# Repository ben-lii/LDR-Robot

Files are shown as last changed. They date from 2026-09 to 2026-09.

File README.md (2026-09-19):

# Teleop robot

Browser-driven Raspberry Pi robot: live WebRTC video and WASD motor control.

Local development and deploy steps will be filled in as the app is built. See `docs/` for architecture, protocol, hardware, and Pi setup.

## Workspaces

- `web/` — Next.js console (Vercel)
- `robot/` — Node server on the Pi
- `packages/protocol` — shared contracts

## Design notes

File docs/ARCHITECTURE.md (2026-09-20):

# Architecture

No database. Users and robots live in validated env JSON on the web app;
runtime drive/media state lives in memory on the robot.

## Planes

1. **Auth / session (web)** — login cookie, control-token minting, ICE list.
   Never on the real-time path except token refresh.
2. **Control (WebSocket)** — browser ↔ robot Node server. Seat, drive, e-stop,
   watchdog. Continuously authorized via hello + `token_refresh`.
3. **Media (WHEP / WebRTC)** — browser POSTs SDP to robot `/whep`; Node checks
   the bearer token once, then proxies to local MediaMTX. An already-running
   video session is **not** continuously re-checked; control is.

## Local media

`MEDIA_MODE=disabled` → `/whep` returns `503 video_unavailable` (UI shows
"Video unavailable"). Laptop webcam testing: see `docs/LOCAL_VIDEO.md`.

## Pi deployment

End-to-end OS / systemd / tunnel steps: `docs/PI_SETUP.md`.  
Wiring and power: `docs/HARDWARE.md`. On the Pi prefer `MOTOR_DRIVER=gpiod`
(`rpi-io` + soft PWM, Trixie-friendly). Legacy `MOTOR_DRIVER=pigpio` remains for
Bookworm / self-built pigpio. Both are optional native deps loaded only via
dynamic import; laptops use `mock`.

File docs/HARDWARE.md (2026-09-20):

# Hardware

Raspberry Pi Zero 2 W teleop robot: camera, mic, DRV8833, two N20 motors.

## Bill of materials (reference)

| Part | Role |
| --- | --- |
| Raspberry Pi Zero 2 W | Compute, Wi‑Fi, GPIO |
| OV5647 camera module | CSI video (H.264 via `rpicam-vid`) |
| I2S MEMS microphone | Robot listen-back audio |
| DRV8833 dual H-bridge | Motor driver |
| 2× N20 gearmotors | Differential / tank drive |
| Separate motor battery + 5 V logic supply | Split rails, **shared ground** |

## GPIO map (BCM) — defaults in `robot/.env`

| Signal | BCM | DRV8833 / notes |
| --- | --- | --- |
| Left IN1 (`PIN_AIN1`) | 5 | PWM or digital |
| Left IN2 (`PIN_AIN2`) | 6 | PWM or digital |
| Right IN1 (`PIN_BIN1`) | 13 | PWM or digital |
| Right IN2 (`PIN_BIN2`) | 26 | PWM or digital |
| nSLEEP (`PIN_SLEEP`) | optional | High = enabled; omit if tied high in hardware |

Verify against your board silkscreen before powering motors. Change pins only via env — never hard-code elsewhere.

## Motor polarity

Software can fix wiring mistakes without rewiring:

- `INVERT_LEFT` / `INVERT_RIGHT` — flip that side’s sign  
- `SWAP_MOTORS` — swap left/right after mix  

`MIN_DRIVE_DUTY` (default `0.25`) lifts small commands so N20s overcome stiction.
`PWM_FREQUENCY_HZ` defaults to `1000`; with `MOTOR_DRIVER=gpiod` soft PWM is
clamped to 400 Hz (userspace timers). `pigpio` may round to a supported rate.

## Drive truth table (DRV8833)

| Mode | IN1 | IN2 |
| --- | --- | --- |
| Forward | PWM | LOW |
| Reverse | LOW | PWM |
| Coast | LOW | LOW |
| Brake | HIGH | HIGH |

## Power (critical)

- **Logic rail** (Pi 5 V / 3.3 V GPIO) and **motor rail** (battery → VMOT on DRV8833) must be separate supplies.  
- **Connect grounds together** (common GND).  
- Never power motors from the Pi 5 V pin.  
- Add bulk capacitance near the DRV8833 VMOT pins as the module recommends.  
- Fit a physical kill switch / fuse on the motor battery.

## Camera / audio

- Enable camera (and legacy stack notes) in `infra/pi/config.txt.notes.md`.  
- Mic device name is tuned in `/etc/teleop/av.env` (`AUDIO_DEVICE`). Start with `AUDIO_ENABLED=0` until video is stable.

## Safety

- Software watchdog (~300 ms) and e-stop live on the Pi.  
- Hardware still needs a way to cut motor power if software hangs.

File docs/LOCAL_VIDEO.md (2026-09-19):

# Local video test (laptop webcam → MediaMTX → teleop UI)

Yes — you can exercise the full WHEP path on a Windows laptop without a Pi
camera. Publish your webcam (or a test pattern) into MediaMTX, point the robot
proxy at it, and open the console.

## Prerequisites

1. [ffmpeg](https://ffmpeg.org/download.html) on your PATH  
2. [MediaMTX](https://github.com/bluenviron/mediamtx/releases) **v1.12.2** (or
   the pin in `infra/mediamtx/mediamtx.yml`)  
3. Robot + web already working (`npm run dev:robot`, `npm run dev:web`)

## 1. Start MediaMTX

From the repo root:

```powershell
# Download the release zip once, extract mediamtx.exe somewhere on PATH, then:
mediamtx .\infra\mediamtx\mediamtx.yml
```

Leave this terminal open. API: `127.0.0.1:9997`, WHEP: `127.0.0.1:8889`,
RTSP publish: `127.0.0.1:8554`.

## 2. Publish the webcam

List DirectShow devices:

```powershell
ffmpeg -list_devices true -f dshow -i dummy
```

Publish (replace the quoted names with yours):

```powershell
ffmpeg -f dshow -video_size 640x480 -framerate 30 `
  -i video="Integrated Camera" `
  -pix_fmt yuv420p `
  -c:v libx264 -profile:v baseline -bf 0 -g 30 -preset ultrafast -tune zerolatency `
  -f rtsp -rtsp_transport tcp rtsp://127.0.0.1:8554/robot
```

Many webcams deliver YUY2 (4:2:2); baseline H.264 needs `yuv420p` — without
`-pix_fmt yuv420p` you'll see `baseline profile doesn't support 4:2:2`.

Video-only is fine. To include a mic, add a second `-i audio="…"` and
`-c:a libopus -ac 1 -b:a 32k`.

No camera? Use a test pattern instead:

```powershell
ffmpeg -re -f lavfi -i testsrc=size=640x480:rate=30 `
  -pix_fmt yuv420p `
  -c:v libx264 -profile:v baseline -bf 0 -g 30 -preset ultrafast -tune zerolatency `
  -f rtsp -rtsp_transport tcp rtsp://127.0.0.1:8554/robot
```

## 3. Enable media on the robot

In `robot/.env`:

```env
MEDIA_MODE=mediamtx
MEDIAMTX_WHEP_URL=http://127.0.0.1:8889
MEDIAMTX_API_URL=http://127.0.0.1:9997
MEDIA_PATH=robot
```

Restart `npm run dev:robot`. Confirm MediaMTX sees the path:

```powershell
curl.exe http://127.0.0.1:9997/v3/paths/get/robot
```

`ready` should be `true` while ffmpeg is publishing.

## 4. Watch in the browser

Open the console (already logged in). You should see **Live** once frames
decode. Click the mic button to unmute robot audio (starts muted for autoplay).

If the badge stays on **Video unavailable**, check `MEDIA_MODE`, that MediaMTX
is running, and that `ALLOWED_ORIGINS` includes `http://localhost:3000`.

## Notes

- Browser ↔ MediaMTX **media** uses UDP **8189** (same machine → usually fine).
  Remote viewers need TURN and/or a forward of UDP 8189 (see TROUBLESHOOTING).
- Token is checked when WHEP connects; an existing video session is not
  continuously re-authorized (control WS is). See ARCHITECTURE.md.

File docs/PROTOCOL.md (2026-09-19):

# Protocol

All WebSocket messages, token claims, HTTP bodies, and shared constants live in `@teleop/protocol`. Both the web app and the robot import this package. Every message is a JSON text frame with `v: 1` and a `type` discriminator.

Unknown `type` values, extra fields on WebSocket messages, out-of-range numbers, oversize frames (`> 2048` bytes), and garbage JSON are rejected. Parsers return a `Result` and never throw.

## Constants

| Name | Value | Meaning |
| --- | ---: | --- |
| `PROTOCOL_VERSION` | `1` | Message `v` field |
| `WS_PATH` | `/ws` | Control WebSocket |
| `WHEP_PATH` | `/whep` | Authenticated WHEP proxy |
| `STATUS_PATH` | `/status` | Authenticated robot status |
| `HEALTH_PATH` | `/healthz` | Unauthenticated liveness |
| `TOKEN_ISSUER` | `teleop-web` | JWT `iss` |
| `TOKEN_ALG` | `ES256` | Control-token algorithm |
| `TOKEN_TTL_S` | `45` | Control-token lifetime |
| `TOKEN_REFRESH_S` | `15` | Client refresh interval |
| `DRIVER_IDLE_RELEASE_S` | `300` | Idle driver releases the seat  |
| `SESSION_COOKIE_NAME` | `teleop_session` | Web login cookie |
| `SESSION_MAX_AGE_S` | `604800` | Login cookie lifetime (7 days) |
| `DRIVE_SEND_HZ` | `20` | Drive command rate |
| `PING_INTERVAL_MS` | `2000` | WebSocket ping interval |
| `DEFAULT_WATCHDOG_MS` | `300` | Motor watchdog |
| `AUTH_TIMEOUT_MS` | `3000` | Time to send `hello` |
| `MAX_WS_MESSAGE_BYTES` | `2048` | Max text-frame size |
| `MAX_WS_MSG_PER_SEC` | `60` | Per-connection rate limit |
| `VIEWER_CAN_ESTOP` | `true` | Viewers may engage e-stop |
| `STATUS_POLL_MS` | `5000` | Browser `/status` poll |
| `OFFLINE_AFTER_FAILED_POLLS` | `2` | Consecutive failures → offline |

WebSocket close codes: `UNAUTHORIZED` 4001, `TOKEN_EXPIRED` 4002, `PROTOCOL_ERROR` 4003, `AUTH_TIMEOUT` 4008, `SUPERSEDED` 4009, `SERVER_BUSY` 4010.

## Client → robot

### `hello`

Must be the first message. The token is never sent in the URL.

```json
{
  "v": 1,
  "type": "hello",
  "token": "<jwt>",
  "clientSessionId": "550e8400-e29b-41d4-a716-446655440000",
  "wantControl": true
}
```

### `request_control`

Viewer with driver permission asks for the seat.

```json
{ "v": 1, "type": "request_control" }
```

### `release_control`

Driver gives up the seat.

```json
{ "v": 1, "type": "release_control" }
```

### `drive`

Sent at `DRIVE_SEND_HZ` while driving. `steer > 0` is right (D). Each valid `drive` from the driver feeds the watchdog. `throttle` and `steer` are in `[-1, 1]`; `speed` is an integer in `[0, 100]`.

```json
{ "v": 1, "type": "drive", "throttle": 1, "steer": 0, "speed": 50 }
```

### `brake`

Level state. Space held = `true`.

```json
{ "v": 1, "type": "brake", "active": true }
```

### `estop`

`engaged: true` is allowed for any authenticated role when `VIEWER_CAN_ESTOP`. `engaged: false` (clear) is drivers only.

```json
{ "v": 1, "type": "estop", "engaged": true }
```

### `ping`

Client timestamp `t` is echoed in `pong` for RTT.

```json
{ "v": 1, "type": "ping", "id": 1, "t": 1726740000123 }
```

### `token_refresh`

Extends authorization. May lower permission (`driver` → `viewer`).

```json
{ "v": 1, "type": "token_refresh", "token": "<jwt>" }
```

## Robot → client

### `welcome`

```json
{
  "v": 1,
  "type": "welcome",
  "robotId": "7c9e6679-7425-40de-944b-e07fc1f90ae7",
  "permission": "driver",
  "role": "driver",
  "limits": { "watchdogMs": 300, "maxSpeedPercent": 100 },
  "state": {
    "mode": "idle",
    "speedPercent": 0,
    "driverPresent": true,
    "mediaReady": true,
    "uptimeS": 12.5
  }
}
```

`permission` is the most this user may do. `role` is the effective seat (`driver` or `viewer`).

### `role_changed`

`reason` is one of `granted`, `seat_taken`, `released`, `permission`, `token`.

```json
{ "v": 1, "type": "role_changed", "role": "viewer", "reason": "seat_taken" }
```

### `state`

Sent on change and every 1 s. `mode` is `idle` | `driving` | `braking` | `estop` | `fault`.

```json
{
  "v": 1,
  "type": "state",
  "state": {
    "mode": "driving",
    "speedPercent": 40,
    "driverPresent": true,
    "mediaReady": true,
    "uptimeS": 88
  }
}
```

### `pong`

```json
{ "v": 1, "type": "pong", "id": 1, "t": 1726740000123 }
```

### `error`

`code` is `UNAUTHORIZED` | `TOKEN_EXPIRED` | `FORBIDDEN_ROLE` | `DRIVER_BUSY` | `BAD_MESSAGE` | `RATE_LIMITED` | `ROBOT_FAULT`.

```json
{
  "v": 1,
  "type": "error",
  "code": "DRIVER_BUSY",
  "message": "Another driver holds the seat",
  "fatal": false
}
```

## Control token (JWT, ES256)

Claims:

| Claim | Meaning |
| --- | --- |
| `iss` | `teleop-web` |
| `aud` | `robot:<robotId>` (exactly one robot) |
| `sub` | user email |
| `perm` | `driver` or `viewer` (maximum allowed)  |
| `sid` | client session id (uuid, one per tab) |
| `jti` | random uuid |
| `iat`, `exp` | unix seconds; `exp = iat + TOKEN_TTL_S` |

Use `audienceFor(robotId)` to build `aud`.

## HTTP: login

`POST /api/auth/login`

```json
{ "email": "me@example.com", "password": "secret" }
```

Non-2xx body for all web APIs:

```json
{ "error": "unauthenticated" }
```

`error` is `unauthenticated` | `not_found` | `bad_request` | `rate_limited` | `server_error`.

## HTTP: session

`POST /api/robots/[slug]/session`

Request:

```json
{ "clientSessionId": "550e8400-e29b-41d4-a716-446655440000" }
```

Response:

```json
{
  "robot": {
    "id": "7c9e6679-7425-40de-944b-e07fc1f90ae7",
    "slug": "robot-1",
    "name": "Robot 1"
  },
  "permission": "driver",
  "token": "<jwt>",
  "tokenExpiresAt": "2026-09-19T13:00:00.000Z",
  "urls": {
    "ws": "wss://robot-1.example.com/ws",
    "whep": "https://robot-1.example.com/whep",
    "status": "https://robot-1.example.com/status"
  },
  "iceServers": [{ "urls": "stun:stun.l.google.com:19302" }],
  "serverTime": "2026-09-19T12:59:15.000Z"
}
```

## HTTP: robot status

`GET /status` (bearer token required)

```json
{
  "v": 1,
  "fwVersion": "0.0.0",
  "uptimeS": 88,
  "mode": "idle",
  "driverPresent": false,
  "mediaReady": true,
  "clockSynced": true,
  "cpuTempC": 47.2,
  "load1": 0.31,
  "memFreeMb": 220,
  "wifiRssiDbm": -62
}
```

Telemetry fields are `null` when unavailable.

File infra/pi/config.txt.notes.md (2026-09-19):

# Notes for /boot/firmware/config.txt (Bookworm) or /boot/config.txt (older).
# Apply, then reboot. Exact lines vary by camera overlay package — verify against
# Raspberry Pi docs for your OS image.

## Camera (OV5647 / CSI)

# Bookworm typically:
#   camera_auto_detect=1
# Or legacy:
#   start_x=1
#   gpu_mem=128
#
# Confirm with: rpicam-hello --list-cameras

## I2S microphone

# Enable I2S and load your codec overlay (board-specific), e.g.:
#   dtparam=i2s=on
#   dtoverlay=googlevoicehat-soundcard
# or whatever overlay your mic HAT documents.
#
# List capture devices after reboot: arecord -l
# Put the device string into /etc/teleop/av.env as AUDIO_DEVICE.

## Performance (optional on Zero 2 W)

#   arm_boost=1

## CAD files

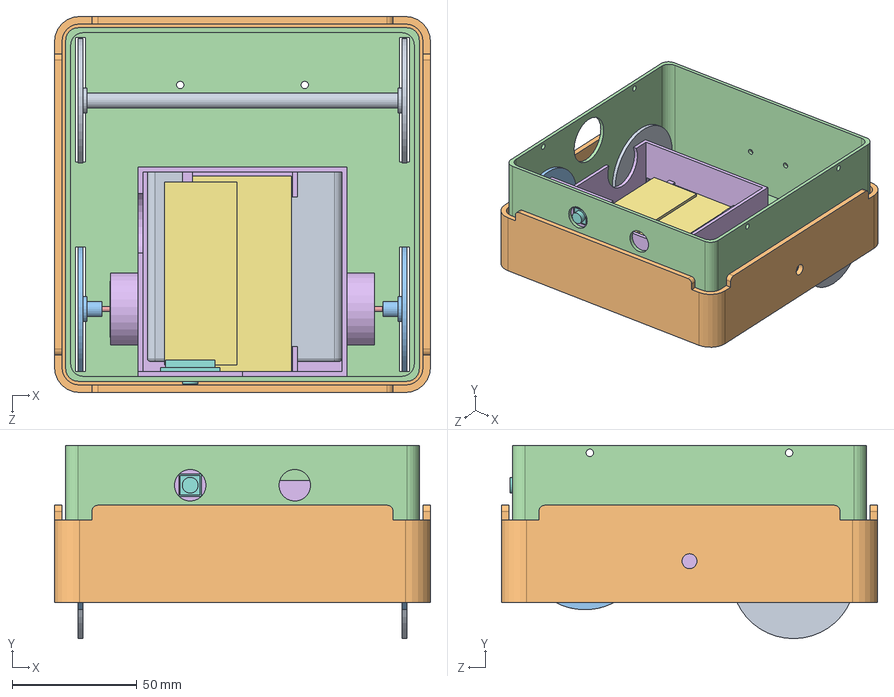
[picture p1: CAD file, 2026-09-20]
Solidworks/whole_robot.SLDASM
151.0 x 77.6 x 151.0 mm
battery
camera_arducam
circut_board
electrical_rig
new_motor x 2
base
bigger_press_fit_wheel x 2
shirt
stabilizer_wheels_2

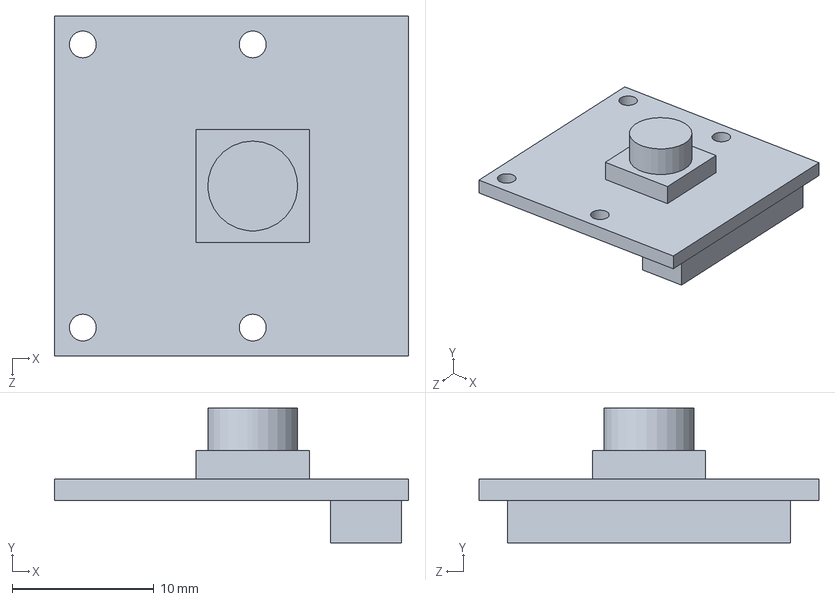
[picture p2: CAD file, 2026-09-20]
Solidworks/camera_arducam.SLDPRT
25.0 x 9.50 x 24.0 mm

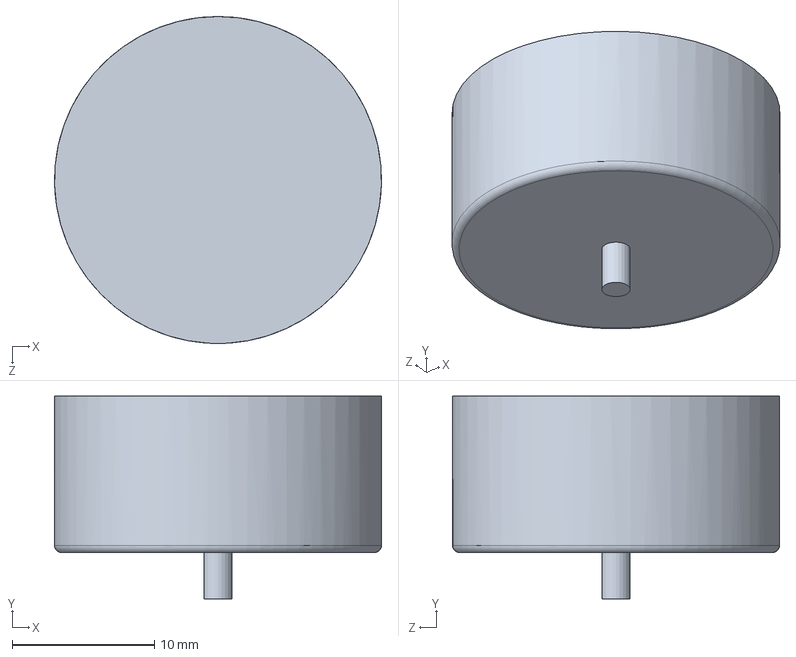
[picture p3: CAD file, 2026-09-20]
Solidworks/new_motor.SLDPRT
23.0 x 14.2 x 23.0 mm

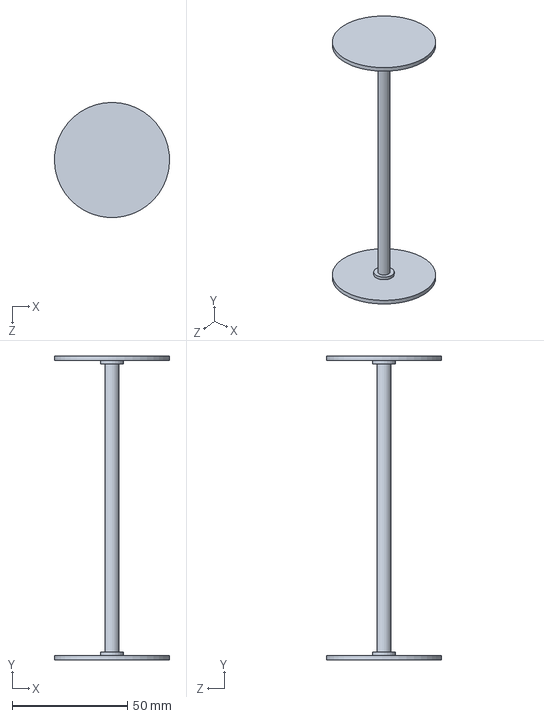
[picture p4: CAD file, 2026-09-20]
Solidworks/stabilizer_wheels_2.SLDPRT
50.0 x 132.0 x 50.0 mm

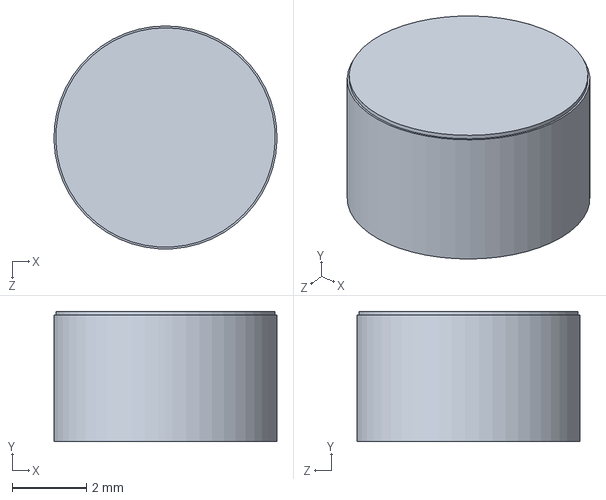
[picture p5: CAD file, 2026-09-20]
Solidworks/microphone.SLDPRT
6.00 x 3.50 x 6.00 mm

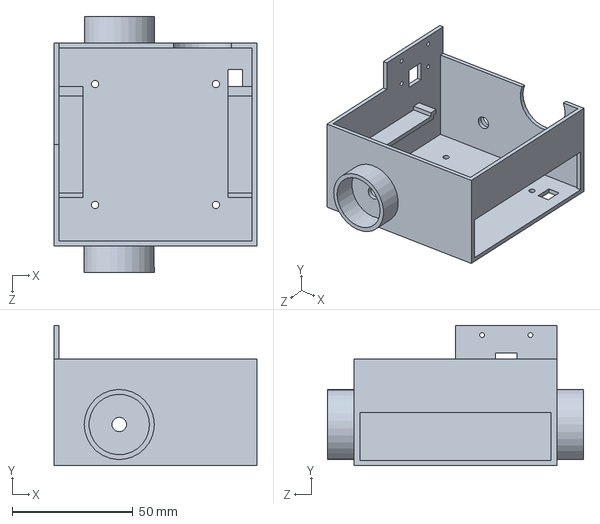
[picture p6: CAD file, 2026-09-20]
Solidworks/electrical_rig.SLDPRT
84.0 x 58.0 x 106.0 mm

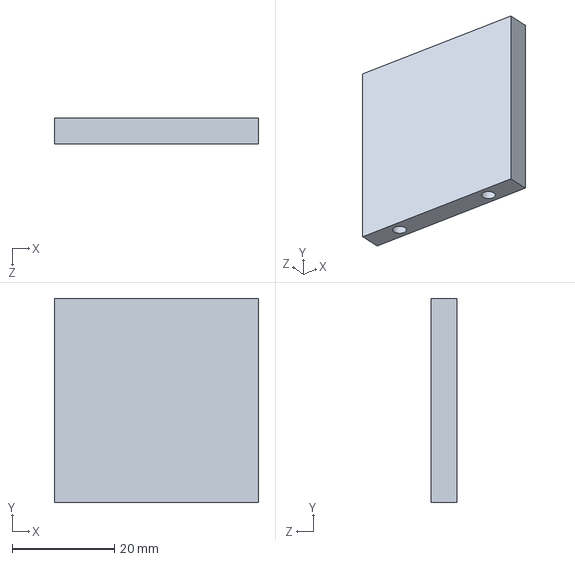
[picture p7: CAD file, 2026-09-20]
Solidworks/slab.SLDPRT
40.0 x 40.0 x 5.00 mm

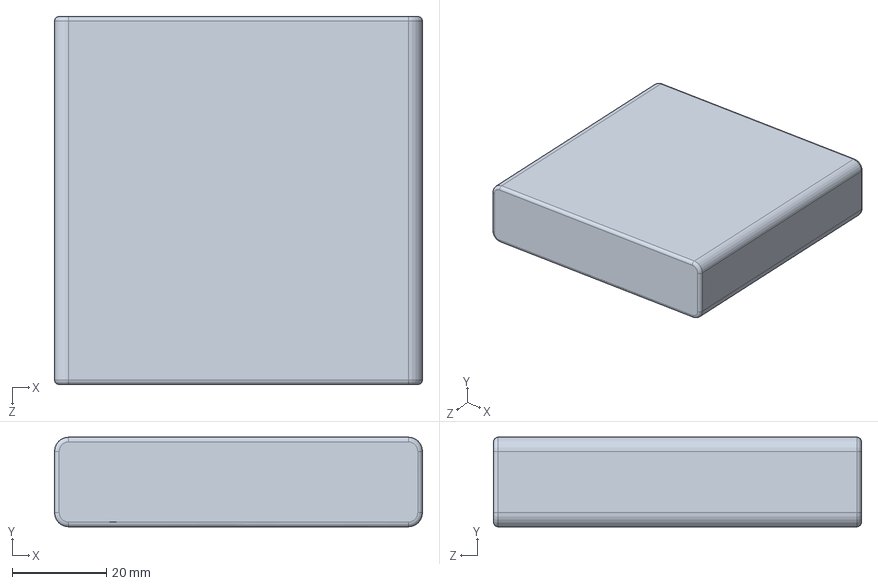
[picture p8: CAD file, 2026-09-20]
Solidworks/battery.SLDPRT
78.0 x 19.0 x 78.0 mm

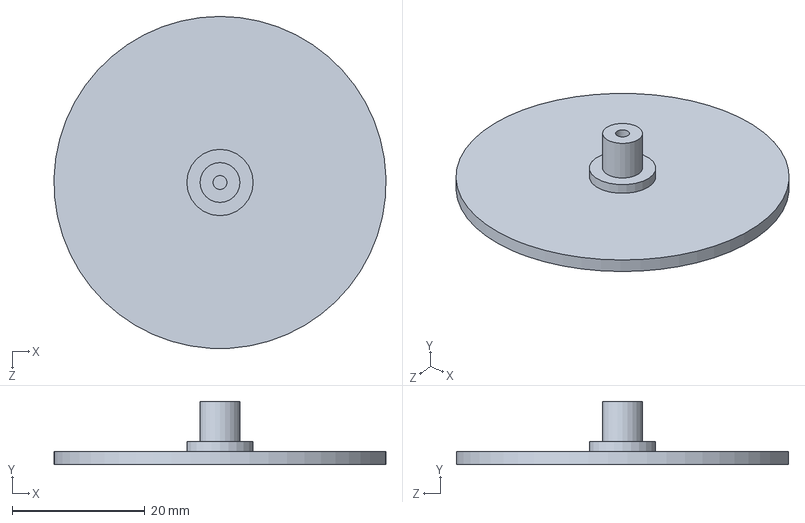
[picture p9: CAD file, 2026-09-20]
Solidworks/bigger_press_fit_wheel.SLDPRT
50.0 x 9.50 x 50.0 mm

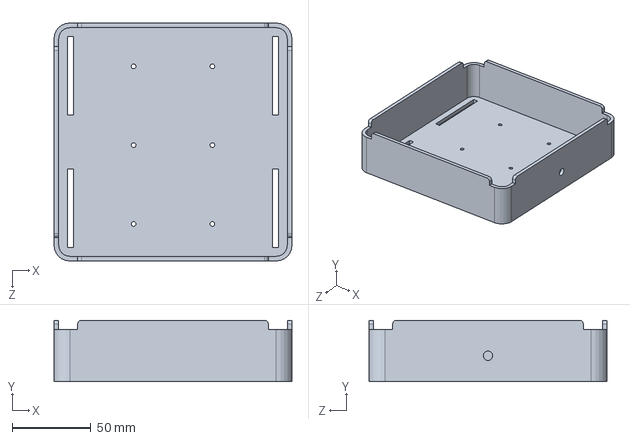
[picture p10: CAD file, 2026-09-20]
Solidworks/shirt.SLDPRT
151.0 x 39.0 x 151.0 mm

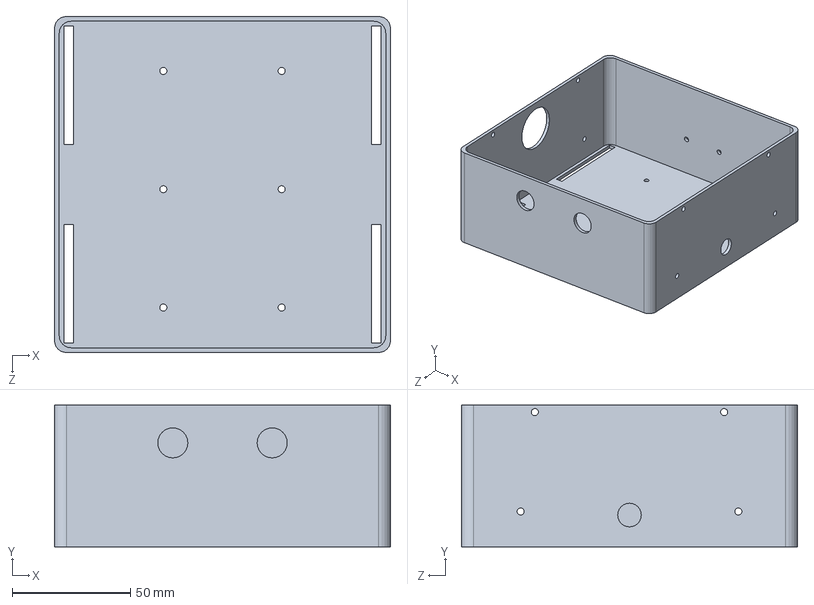
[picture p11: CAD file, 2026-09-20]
Solidworks/base.SLDPRT
142.0 x 60.0 x 142.0 mm

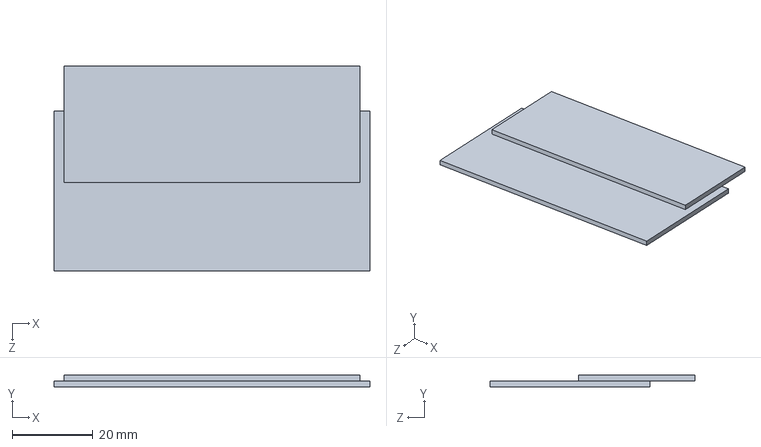
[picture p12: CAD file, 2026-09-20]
Solidworks/circut_board.SLDPRT
78.5 x 3.00 x 51.0 mm

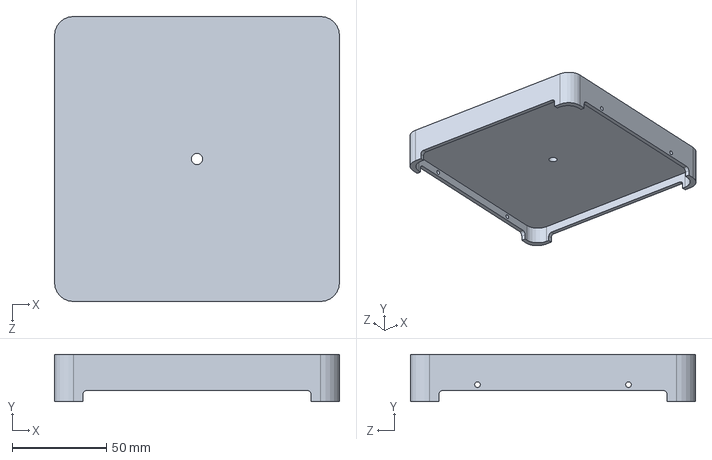
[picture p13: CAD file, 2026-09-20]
Solidworks/helmet.SLDPRT
151.0 x 25.0 x 151.0 mm

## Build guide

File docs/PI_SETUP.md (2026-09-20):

# Raspberry Pi setup (end-to-end)

Fresh **Raspberry Pi OS Lite 64-bit (Bookworm)** on a **Zero 2 W**.  
Hardware wiring: `docs/HARDWARE.md`. Laptop webcam testing: `docs/LOCAL_VIDEO.md`.

## 0. Accounts / hostnames you need first

1. A Vercel deploy of `web/` with `AUTH_USERS_JSON`, `ROBOTS_JSON`, signing keys.  
2. A Cloudflare account + domain. Create a **tunnel** whose public hostname is the same as `tunnelHost` in `ROBOTS_JSON` (e.g. `robot-1.yourdomain.com`) → `http://127.0.0.1:8080`.  
3. On the PC: `npm run secrets:generate` — keep `ROBOT_ID` + public JWK for the Pi, private JWK + session secret for Vercel only.

## 1. Base OS

```bash
sudo apt update && sudo apt full-upgrade -y
sudo apt install -y git curl build-essential python3-dev
# Node 22 (nodesource or fnm/nvm — match engines in package.json)
curl -fsSL https://deb.nodesource.com/setup_22.x | sudo -E bash -
sudo apt install -y nodejs
```

Create a service user:

```bash
sudo useradd -r -m -s /bin/bash teleop
sudo usermod -aG video,gpio,i2c,spi teleop   # adjust groups as needed
```

Enable camera / I2S using the notes in `infra/pi/config.txt.notes.md`, then reboot.

## 2. GPIO / motors (Trixie: gpiod, not pigpio)

`pigpio` is **not** in Raspberry Pi OS Trixie. Use **`MOTOR_DRIVER=gpiod`**:
libgpiod via the optional `rpi-io` npm package, plus userspace software PWM
(any BCM pins from `PIN_*`).

```bash
sudo apt install -y libgpiod-dev gpiod build-essential python3
# teleop user must be in the gpio group (see §1)
```

Optional legacy (Bookworm / self-built pigpio only):

```bash
# Only if pigpio packages or a from-source build are available:
# sudo apt install -y pigpio && sudo systemctl enable --now pigpiod
# then MOTOR_DRIVER=pigpio
```

The Node bindings (`rpi-io`, optionally `pigpio`) are **optionalDependencies** of
`robot/` — they only install cleanly on the Pi.
## 3. Clone and build

**Recommended on a Zero 2 W:** build on your PC, copy artifacts (skip full-repo `npm ci` on the Pi — it often OOMs).

### 3a. On your PC (PowerShell)

```powershell
cd C:\Users\silly\Documents\LDR-Robot
npm run build -w robot
```

### 3b. On the Pi (once)

```bash
sudo mkdir -p /opt/teleop/robot
sudo chown -R teleop:teleop /opt/teleop
```

### 3c. Copy from PC → Pi

Replace `PI_IP` (e.g. `192.168.1.42`) and use the `teleop` user (or your pi user, then `chown`):

```powershell
scp -r robot\dist teleop@PI_IP:/opt/teleop/robot/
scp robot\package.runtime.json teleop@PI_IP:/opt/teleop/robot/package.json
```

### 3d. On the Pi — production deps only

```bash
cd /opt/teleop/robot
sudo -u teleop npm install --omit=dev
# If rpi-io failed to build: sudo apt install -y libgpiod-dev gpiod build-essential
# then: cd /opt/teleop/robot/node_modules/rpi-io && sudo -u teleop npm install
```

### Alternative: build on the Pi (slow / needs swap)

```bash
sudo mkdir -p /opt/teleop && sudo chown teleop:teleop /opt/teleop
sudo -u teleop git clone <your-repo-url> /opt/teleop/src
cd /opt/teleop/src
sudo -u teleop npm ci
sudo -u teleop npm run build -w @teleop/protocol -w robot
sudo -u teleop mkdir -p /opt/teleop/robot
sudo -u teleop cp -r robot/dist robot/package.json /opt/teleop/robot/
# Prefer package.runtime.json as package.json on the Pi (no workspace @teleop/protocol):
sudo -u teleop cp robot/package.runtime.json /opt/teleop/robot/package.json
cd /opt/teleop/robot && sudo -u teleop npm install --omit=dev
```

## 4. Env files

```bash
sudo mkdir -p /etc/teleop
sudo cp /opt/teleop/src/infra/pi/robot.env.example /etc/teleop/robot.env
sudo cp /opt/teleop/src/infra/pi/av.env.example /etc/teleop/av.env
sudo cp /opt/teleop/src/infra/mediamtx/mediamtx.yml /etc/teleop/mediamtx.yml
sudo chmod 600 /etc/teleop/robot.env
```

Edit `/etc/teleop/robot.env`:

- `ROBOT_ID` = UUID from secrets (must match `ROBOTS_JSON[].id`)  
- `TOKEN_PUBLIC_JWK` = public JWK only  
- `ALLOWED_ORIGINS` = your Vercel origin(s), comma-separated  
- `MOTOR_DRIVER=gpiod`  
- `MEDIA_MODE=mediamtx`  
- Pin / invert / swap as needed (`docs/HARDWARE.md`)

Edit `/etc/teleop/av.env` — start with `AUDIO_ENABLED=0`.

## 5. MediaMTX

Pin: **MediaMTX v1.12.2** (see comment in `infra/mediamtx/mediamtx.yml`).

```bash
# Download the linux_arm64 (or armv7) release asset for v1.12.2 from GitHub,
# extract `mediamtx` → /usr/local/bin/mediamtx, chmod +x
sudo cp /opt/teleop/src/infra/systemd/mediamtx.service /etc/systemd/system/
sudo systemctl daemon-reload
sudo systemctl enable --now mediamtx
curl -sS http://127.0.0.1:9997/v3/config/global/get | head
```

## 6. AV publisher

```bash
sudo cp /opt/teleop/src/infra/pi/av-stream.sh /usr/local/bin/teleop-av-stream.sh
sudo chmod +x /usr/local/bin/teleop-av-stream.sh
sudo cp /opt/teleop/src/infra/systemd/teleop-av.service /etc/systemd/system/
sudo systemctl daemon-reload
sudo systemctl enable --now teleop-av
```

Confirm path ready: `curl -sS http://127.0.0.1:9997/v3/paths/get/robot`

## 7. Robot Node service

```bash
sudo cp /opt/teleop/src/infra/systemd/teleop-robot.service /etc/systemd/system/
sudo systemctl daemon-reload
sudo systemctl enable --now teleop-robot
curl -sS http://127.0.0.1:8080/healthz
```

## 8. Cloudflare tunnel (`cloudflared`)

1. Install `cloudflared` for ARM from Cloudflare’s packages.  
2. Authenticate / create a tunnel (dashboard or `cloudflared tunnel create teleop-robot-1`).  
3. Copy `infra/cloudflared/config.example.yml` → `/etc/cloudflared/config.yml`, fill tunnel UUID + credentials file path, keep ingress to `http://127.0.0.1:8080`.  
4. Route DNS: `cloudflared tunnel route dns <tunnel> robot-1.yourdomain.com`  
5. Install as a service: `sudo cloudflared service install` (or use `infra/systemd/cloudflared.service`).  
6. `sudo systemctl enable --now cloudflared`

HTTPS/WSS for control + WHEP signaling go through the tunnel. **WebRTC media is UDP** (port **8189** on the Pi). Same-LAN often works with STUN; remote viewers usually need TURN (`ICE_TURN_*` or Cloudflare TURN on the web app) and/or a UDP 8189 forward — see `docs/TROUBLESHOOTING.md`.

## 9. Verify

1. From your laptop: open the Vercel app, log in, open Robot 1.  
2. Status badge **Online**, role **You're driving**.  
3. Video **Live** (mic button unmutes).  
4. WASD → motors move; Space brake; Stop e-stop / Resume.  
5. Kill Wi‑Fi briefly → motors stop via watchdog; reconnect recovers.

## 10. Updates

```bash
cd /opt/teleop/src && sudo -u teleop git pull
sudo -u teleop npm ci && sudo -u teleop npm run build -w robot
sudo -u teleop cp -r robot/dist/* /opt/teleop/robot/dist/
sudo systemctl restart teleop-robot
```

Redeploy Vercel whenever `AUTH_USERS_JSON` / `ROBOTS_JSON` / keys change.

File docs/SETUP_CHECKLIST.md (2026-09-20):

# Setup checklist

Things you must do by hand, in order. Later phases add Vercel, Cloudflare, and Pi steps.

## Important trade-off (no database)

Users and robots live in Vercel / `.env` JSON (`AUTH_USERS_JSON`, `ROBOTS_JSON`).
**Adding, removing, or changing a user or robot means editing that env var and redeploying** the web app. There is no admin UI and no runtime user table.

---

## 1. Generate secrets

From the repo root:

```bash
npm run secrets:generate
```

This prints `.env`-style lines to stdout only (it never writes files):

| Line | Where it goes |
| --- | --- |
| `SESSION_SECRET` | `web/.env.local` and Vercel |
| `TOKEN_SIGNING_PRIVATE_JWK` | `web/.env.local` and Vercel **only** |
| `TOKEN_PUBLIC_JWK` | `robot/.env` (and `/etc/teleop/robot.env` on the Pi) |
| `ROBOT_ID` | `robot/.env` **and** the `"id"` field inside `ROBOTS_JSON` |

Do not commit these values. Do not paste the private JWK or `SESSION_SECRET` into the robot env or into chat.

---

## 2. Hash passwords and build `AUTH_USERS_JSON`

For each person who should log in:

```bash
npm run user:hash
```

The script asks for email, permission (`driver` or `viewer`), robot access (slug list or `*`), and a password (hidden, not stored in shell history). It prints:

1. A `passwordHash` string (`scrypt$16384$8$1$…`)
2. A ready-to-paste user JSON object

Assemble a JSON **array** of those objects into a **single line** for `AUTH_USERS_JSON`.

**Critical for `.env.local`:** escape every `$` in `passwordHash` as `\$`.
Next/dotenv treats bare `$16384` as variable expansion and corrupts the hash
(login then fails with `password hash must have 6 $-separated parts`).

Bad:  `"passwordHash":"scrypt$16384$8$1$…"`
Good: `"passwordHash":"scrypt\$16384\$8\$1\$…"`  (every `$` → `\$`)

Example shape (shown unescaped for readability — escape `$` when pasting into `.env`):

```json
[
  {
    "email": "me@example.com",
    "passwordHash": "scrypt$16384$8$1$…",
    "permission": "driver",
    "robots": ["robot-1"]
  },
  {
    "email": "friend@example.com",
    "passwordHash": "scrypt$16384$8$1$…",
    "permission": "viewer",
    "robots": "*"
  }
]
```

Emails are matched case-insensitively. `robots` is either `"*"` or a list of slugs from `ROBOTS_JSON`.

---

## 3. Fill `web/.env.local`

1. Copy `web/.env.example` → `web/.env.local`
2. Paste `SESSION_SECRET` and `TOKEN_SIGNING_PRIVATE_JWK` from step 1
3. Paste your one-line `AUTH_USERS_JSON` from step 2
4. Set `ROBOTS_JSON` (one-line array). Use the same `ROBOT_ID` from step 1 as each robot’s `"id"`. `tunnelHost` is a hostname only (e.g. `robot-1.yourdomain.com`) — no `https://`, path, or port.
5. Optionally set ICE/TURN and `DEV_ROBOT_ORIGIN_OVERRIDE=http://localhost:8080` for local robot testing

Schema validation (readable field errors) lives in `web/src/lib/env.server.ts` / `env.schemas.ts`.

---

## 4. Fill `robot/.env` (laptop mock)

1. Copy `robot/.env.example` → `robot/.env`
2. Paste `ROBOT_ID` and `TOKEN_PUBLIC_JWK` from step 1
3. Set `ALLOWED_ORIGINS` to include `http://localhost:3000` (and your Vercel origin later)
4. Keep `MOTOR_DRIVER=mock`. Leave `MEDIA_MODE=disabled` until you want video; for laptop webcam testing set `MEDIA_MODE=mediamtx` and follow `docs/LOCAL_VIDEO.md`.

---

## Later (deployment)

- [ ] Vercel project (Root Directory `web`, Node 22); set all `web/.env.example` vars; redeploy when users/robots change  
- [ ] Cloudflare domain + tunnel → `http://127.0.0.1:8080`; hostname = `ROBOTS_JSON.tunnelHost`  
- [ ] Pi: follow `docs/PI_SETUP.md` (gpiod/rpi-io, MediaMTX v1.12.2, AV, robot service, cloudflared)  
- [ ] Wiring / power: `docs/HARDWARE.md`  
- [ ] Optional TURN for remote WebRTC (`docs/TROUBLESHOOTING.md`)  
- [ ] Laptop video without Pi: `docs/LOCAL_VIDEO.md`

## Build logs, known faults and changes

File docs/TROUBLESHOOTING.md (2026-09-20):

# Troubleshooting

Symptom → cause → fix table will grow in later phases.

| Symptom | Cause | Fix |
| --- | --- | --- |
| Login returns rate limited after a few tries | In-memory limiter: max 5 failures per IP+email per 10 minutes | Wait, or restart the web process (clears the bucket). On Vercel this is per-instance only — a speed bump, not a hard global lock. |
| Login fails / server error about passwordHash parts | `.env` expanded `$` inside the scrypt hash | In `AUTH_USERS_JSON`, escape each `$` as `\$` (e.g. `scrypt\$16384\$8\$1\$…`). Restart `dev:web`. |
| Session API 401 | Missing/expired login cookie, or user removed from `AUTH_USERS_JSON` | Sign in again; redeploy after editing users. |
| Session API 404 for a robot you expect | Slug missing from `ROBOTS_JSON`, or user `robots` list does not include it | Fix env JSON and restart / redeploy. |
| Console shows Video unavailable | `MEDIA_MODE=disabled`, MediaMTX down, or no publisher on path `robot` | Set `MEDIA_MODE=mediamtx`, start MediaMTX + ffmpeg publisher (see `docs/LOCAL_VIDEO.md`). |
| Video works on LAN, black remotely | NAT/UDP: browser cannot reach WebRTC UDP 8189 on the robot | Add TURN (`ICE_TURN_*` or Cloudflare TURN keys), and/or port-forward UDP 8189 to the Pi. |
| WHEP 503 too_many_viewers | More than `MAX_VIDEO_VIEWERS` concurrent sessions | Close extra tabs, or raise `MAX_VIDEO_VIEWERS` on the robot. |
| `MOTOR_DRIVER=pigpio` / `gpiod` fails on laptop | Native GPIO libs only build/run on the Pi | Keep `MOTOR_DRIVER=mock` locally. On Trixie use `gpiod` + `libgpiod-dev`; `pigpio` is not in Trixie apt. |
| `MOTOR_DRIVER=gpiod` fails on Pi | Missing `rpi-io` / libgpiod / gpio group | `sudo apt install -y libgpiod-dev gpiod`; rebuild `rpi-io`; ensure service user is in `gpio`. |
| Motors silent / one side wrong | Wiring polarity or pin map | Check `docs/HARDWARE.md`; try `INVERT_*` / `SWAP_MOTORS` before rewiring. |
| Tunnel 502 / console Offline | `teleop-robot` or `cloudflared` down, or hostname ≠ `tunnelHost` | `systemctl status teleop-robot cloudflared`; fix DNS/ingress in `infra/cloudflared/config.example.yml`. |
